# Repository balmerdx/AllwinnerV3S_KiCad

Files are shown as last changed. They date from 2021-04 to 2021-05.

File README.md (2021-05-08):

# Balmer Allwinner V3S KICAD scematic & pcb

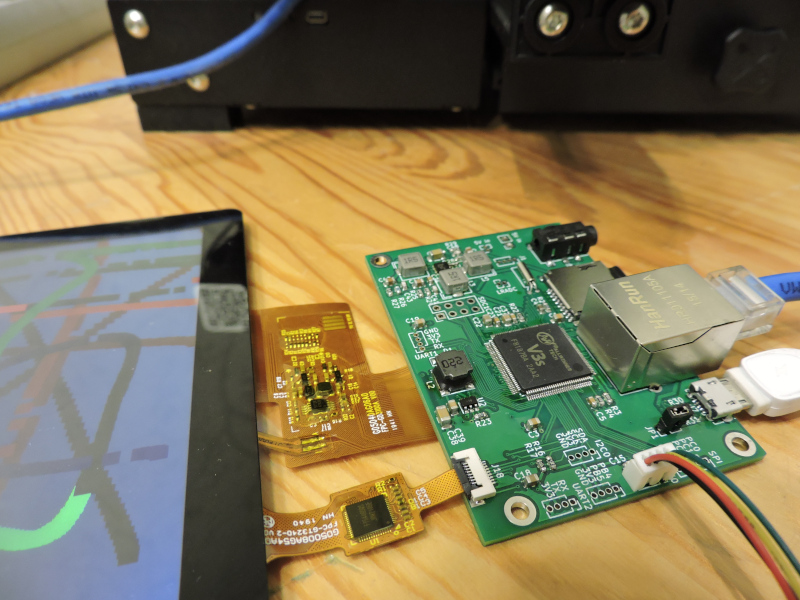
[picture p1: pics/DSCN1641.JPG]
Плата


Allwinner V3S - это пожалуй один из наиболее дешёвых system on chip для embedded linux.

Перечислю его ключевые особенности.
* встроенные 64 мегабайта DRAM
* RGB интерфейс для подключения дисплея
* встроенный PNY для Ethernet 100 Mbit
* USB 2.0 OTG
* встроенный DAC и усилитель для наушников

Это позволяет сделать достаточно дешёвый одноплатник.

Обратите внимание!!!! Плата разведена для Step-Down на EA3036. Микросхема EA3036C имеет несколько другой pinout. К сожалению мне прислали EA3036C, и поэтому на плате есть некрасивое место с её вкорячиванием.

Плата разведена под дисплей с 800x480 с capacitive touch (G05012AG02A1, G050AGZ085A1).

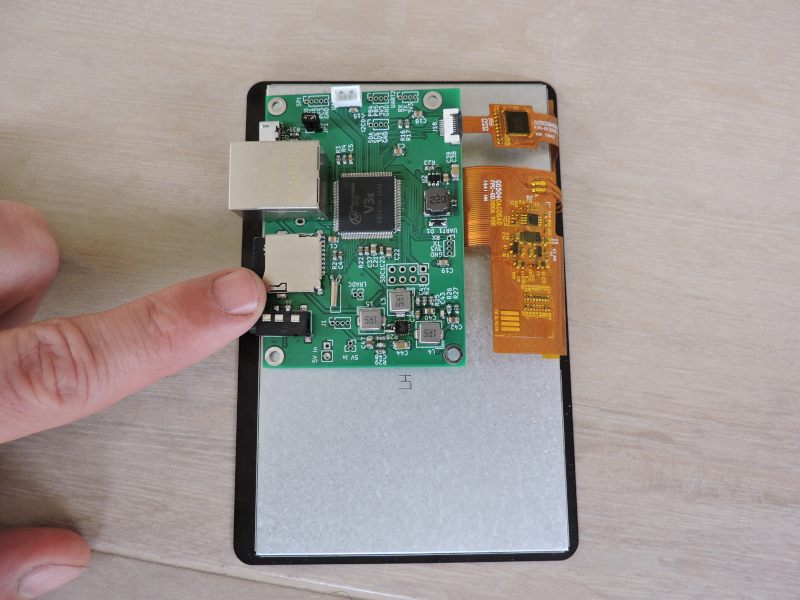
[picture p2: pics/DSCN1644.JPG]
Плата с подключённым дисплеем

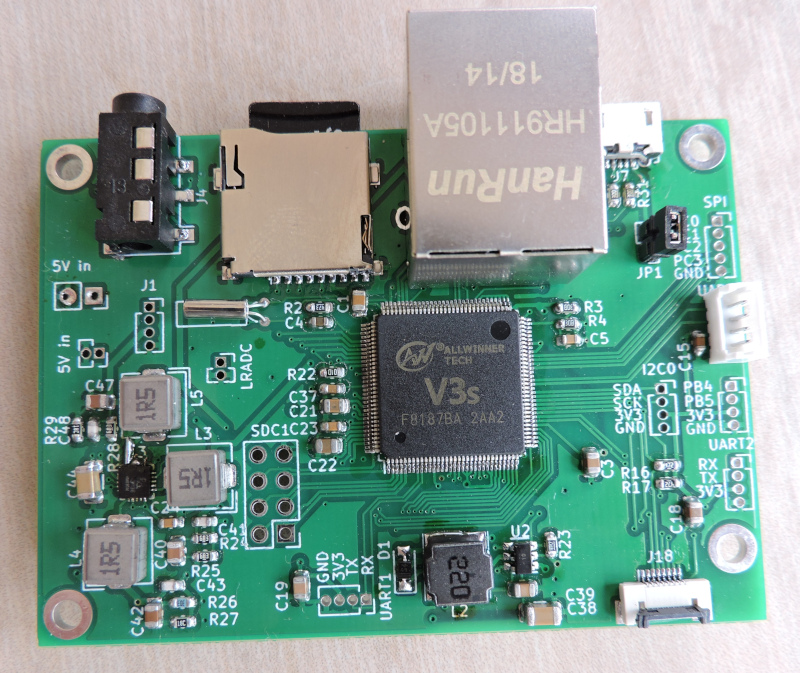
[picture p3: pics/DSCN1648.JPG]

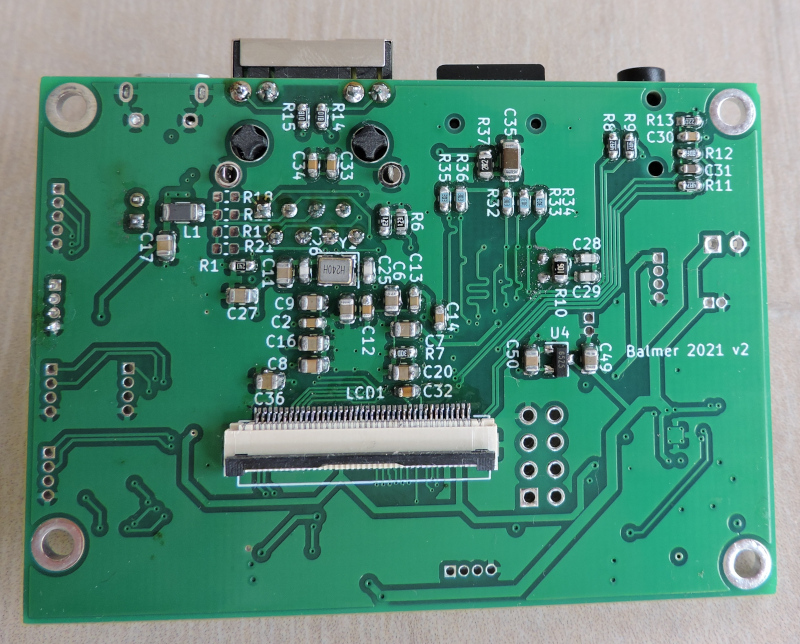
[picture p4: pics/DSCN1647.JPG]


То-же, самое но с корпусом.
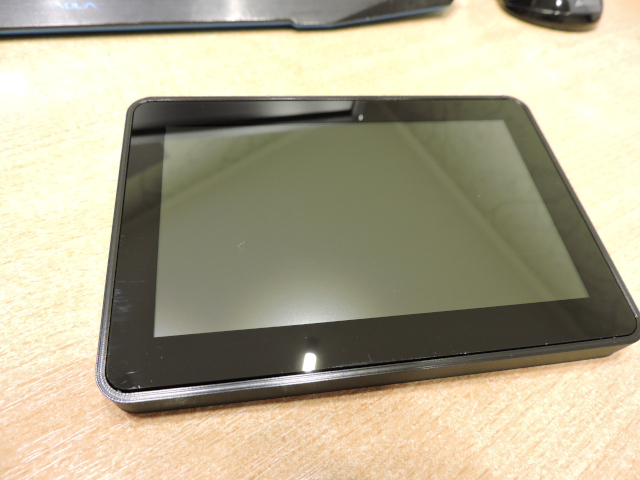
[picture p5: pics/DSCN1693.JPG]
В корпусе сверху

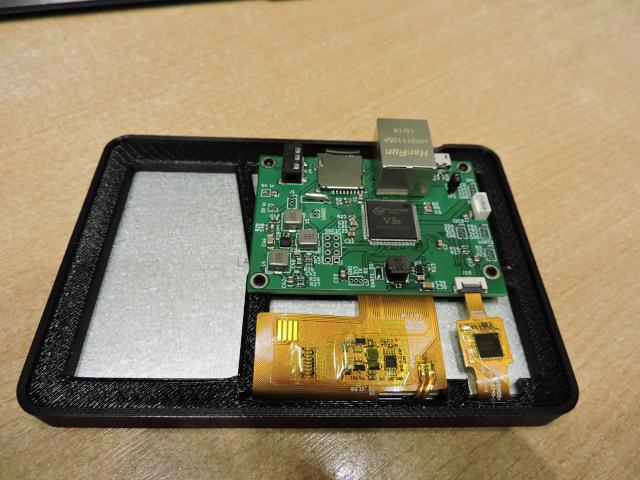
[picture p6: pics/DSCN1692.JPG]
В корпусе снизу


### Сравним с Lichee PI

По размеру мой вариант несколько больше. Но за счёт расположенных разъёмов конечный вариант будет явно компактнее. Разводка Lichee PI мне нравится как пример максимально плотного монтажа. Для отладки это нормально. Но в реальной жизни непонятно, что делать с этими случайным образом раскиданными разъёмами.

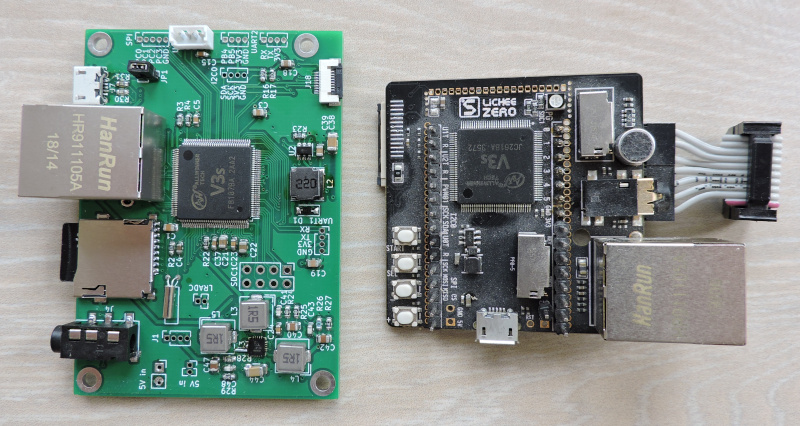
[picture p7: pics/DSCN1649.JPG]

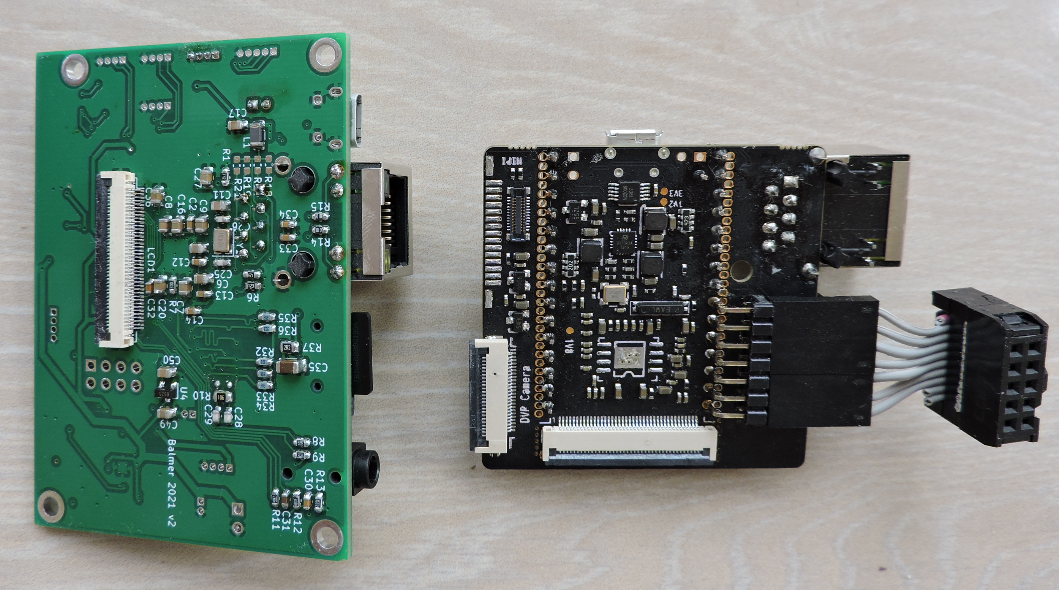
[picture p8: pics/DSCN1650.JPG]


### Информация
* [Схема в pdf формате](info/balmer_allwinner_v3s_v2.pdf)
* [Информация, как собирать linux](info/Buildroot_AllwinnerV3S.pdf)

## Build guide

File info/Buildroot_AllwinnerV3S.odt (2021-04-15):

О настройке buildroot для Allwinner V3S.

Как по порядку настроить buildroot c ядром 4.14 для того, чтобы работал дисплей с capacitive touch touch и WiFi.

Buildroot это достаточно удобная среда, для сборки embedded linux. Она объединяет вместе ядро линукса, uboot и busybox. Ядро 4.14 мне кажется всё ещё достаточно новым. Например Ubuntu, с которой я пишу текст имеет ядро 4.15.

# Первоначальная установка buildroot.

По ссылке https://github.com/Squonk42/buildroot-licheepi-zero есть buildroot заточенный для Allwinner V3S и Lichee PI. Поэтому копируем оттуда основную ветку и в корневой директории пишем:

make licheepi_zero_defconfig

make

И долго долго ждем, когда соберётся первоначальная версия. Она будет без работающего дисплея, но уже с uart/i2c/ethernet(проводной)/LRADC работающими.

Дальше можно проверить, что оно как-то работает.

Записать на SD карту можно например так:

sudo dd if=output/images/sdcard.img of=/dev/sdc bs=4M oflag=dsync

/dev/sdc - это имя вашей sd карты, надо быть акуратнее, чтобы случайно диск какой не отформатировать.

Подключать переходник USB<>UART надо к uart0, это пины IO-B09, IO-B08

После этого можно воткнуть SD карту, включить устройство и подсоединиться используя команды

cu -l /dev/ttyUSB0 -s 115200

screen /dev/ttySUSB0 115200

Login: root

Password: licheepi

# Инициализация дисплея в uboot.

Запускаем

make uboot-nconfig

выставляем такие значения

ARM architecture->

LCD panel timing details (x:800,y:480,depth:18,pclk_khz:33000,le:87,ri:40,up:31,lo:13,hs:1,vs:1,sync:3,vmode:0)

(PB4) LCD Panel backlight PWM

() LCD panel backlight pwm is inverted <- тут не должно быть галочки

Далее компилируем его

make uboot-rebuild

make

После записи на SD карту можно будет увидеть картинку пингвина (это uboot присует) и лог на экране, который уже linux пишет.

(Внимание! PB4 не используется для PWM в плате balmer_allwinner_v3s_v2)

# Настраиваем Capacitive touch screen.

В нашем случае он на FT5446, и для него подходят драйвера ft5x06 которые и так есть в linux. Надо только скомпилировать драйвера и приписать соответсвующие строчки описания железа в dts файл.

Нас интересуют следующие файлы:

sun8i-v3s-licheepi-zero.dts

sun8i-v3s.dtsi

В файле sun8i-v3s.dtsi в секции pio: надо определить секцию

edt_ft5x06_pins: edt_ft5x06_pins@0 {

pins = "PB0", "PB1";

function = "gpio_in";

};

Это наши пины для reset и interrupt для touch screen.

В файле sun8i-v3s-licheepi-zero.dts:

Добавить секцию (и убрать секцию со старым resistive touch в колторой ns2009 драйвера используются)

&i2c0 {

status = "okay";

polytouch: edt-ft5x06@38 {

compatible = "edt,edt-ft5406";

reg = <0x38>;

interrupt-parent = <&pio>;

interrupts = <1 3 IRQ_TYPE_EDGE_FALLING>; //PB3

reset-gpios = <&pio 1 2 GPIO_ACTIVE_LOW>; //PB2

pinctrl-names = "default";

pinctrl-0 = <&edt_ft5x06_pins>;

};

};

Находятся они по таким путям

output/build/linux-zero-4.14.y/arch/arm/boot/dts/sun8i-v3s.dtsi

output/build/linux-zero-4.14.y/arch/arm/boot/dts/sun8i-v3s-licheepi-zero.dts

Так-же надо разрешить наши touch драйвера (и запретить от resistive touch screen)

make linux-nconfig

И ищем там настройки touchscreen.

Device Drivers->Input device support->Touchscreens

Nsiway NS2009 touchscreen - убрать звездочку

EDT FocalTech FT5x06 I2C Touchscreen support - поставить звездочку

после этого пересобираем

make linux-rebuild

make

Touch подключается так (можно по схеме посмотреть)

PB3 - PIN4 INT

PB2 - PIN3 RST

PB6 - PIN6 SCL

PB7 - PIN5 SDA

Ну и GND, VCC соответственно к земле и 3.3V

Само устройство будет по пути.

/dev/input/event1

Можно также запустить на устройстве.

i2cdetect -y 0

и увидеть

0 1 2 3 4 5 6 7 8 9 a b c d e f

00: -- -- -- -- -- -- -- -- -- -- -- -- --

10: -- -- -- -- -- -- -- -- -- -- -- -- -- -- -- --

20: -- -- -- -- -- -- -- -- -- -- -- -- -- -- -- --

30: -- -- -- -- -- -- -- -- UU -- -- -- -- -- -- --

40: -- -- -- -- -- -- -- -- 48 -- -- -- -- -- -- --

50: -- -- -- -- -- -- -- -- -- -- -- -- -- -- -- --

60: -- -- -- -- -- -- -- -- -- -- -- -- -- -- -- --

70: -- -- -- -- -- -- -- --

UU на адресе 0x38 значит, что он используется драйвером Touch.

# Настройка WiFi.

Собственно говоря тут всё работает практически «из коробки». Надо лишь загрузить драйвер r8723bs.ko (т. к. он не встроен в ядро) и настроить wpa_supplicant.

Для этого добавил файл /etc/init.d/S30wifi_driver в процесс загрузки.

Этот файл можно ручками скопировать после сборки. Но лично мне кажется, что лучше встроить это в процесс сборки, тем более buildroot предлагает такой вариант.

В файле .config изменяем на BR2_ROOTFS_OVERLAY="../buildroot_additional/rootfs_overlay" и всё, что в папке rootfs_overlay будет копироваться на наш диск с linux.

Далее, необходимо добавить и настроить wpa_supplicant.

Запускается он в файле rootfs_overlay/etc/network/interfaces

Файл /etc/balmer_SSID.conf - это имя нашей WiFi сети и пароль к ней.

Герерируется этот файл при помощи команды wpa_passphrase wifi_name wifi_password > balmer_SSID.conf

После этого делаем make и в нашем образе диска должны появиться файлы

/etc/balmer_SSID.conf

/etc/init.d/S30wifi_driver

/etc/network/interfaces

После этого WiFi будет запускаться и подключаться в процессе загрузки устройства.

После загрузки можно запустить ifconfig и увидеть, что появился wlan0

wlan0 Link encap:Ethernet HWaddr CC:D2:9B:4B:8C:AD

inet addr:192.168.1.46 Bcast:192.168.1.255 Mask:255.255.255.0

либо воспользоваться командами ping или wget которые есть в сборке по умолчанию.

# Как отключить вывод консоли на экран.

В файле board/licheepi/boot.cmd заменяем первую строчку на такую

setenv bootargs console=ttyS0,115200 panic=5 rootwait consoleblank=0 vt.global_cursor_default=0 root=/dev/mmcblk0p2 earlyprintk rw

Это отключит как вывод консольных сообщений на экран, так и мигающий курсор.

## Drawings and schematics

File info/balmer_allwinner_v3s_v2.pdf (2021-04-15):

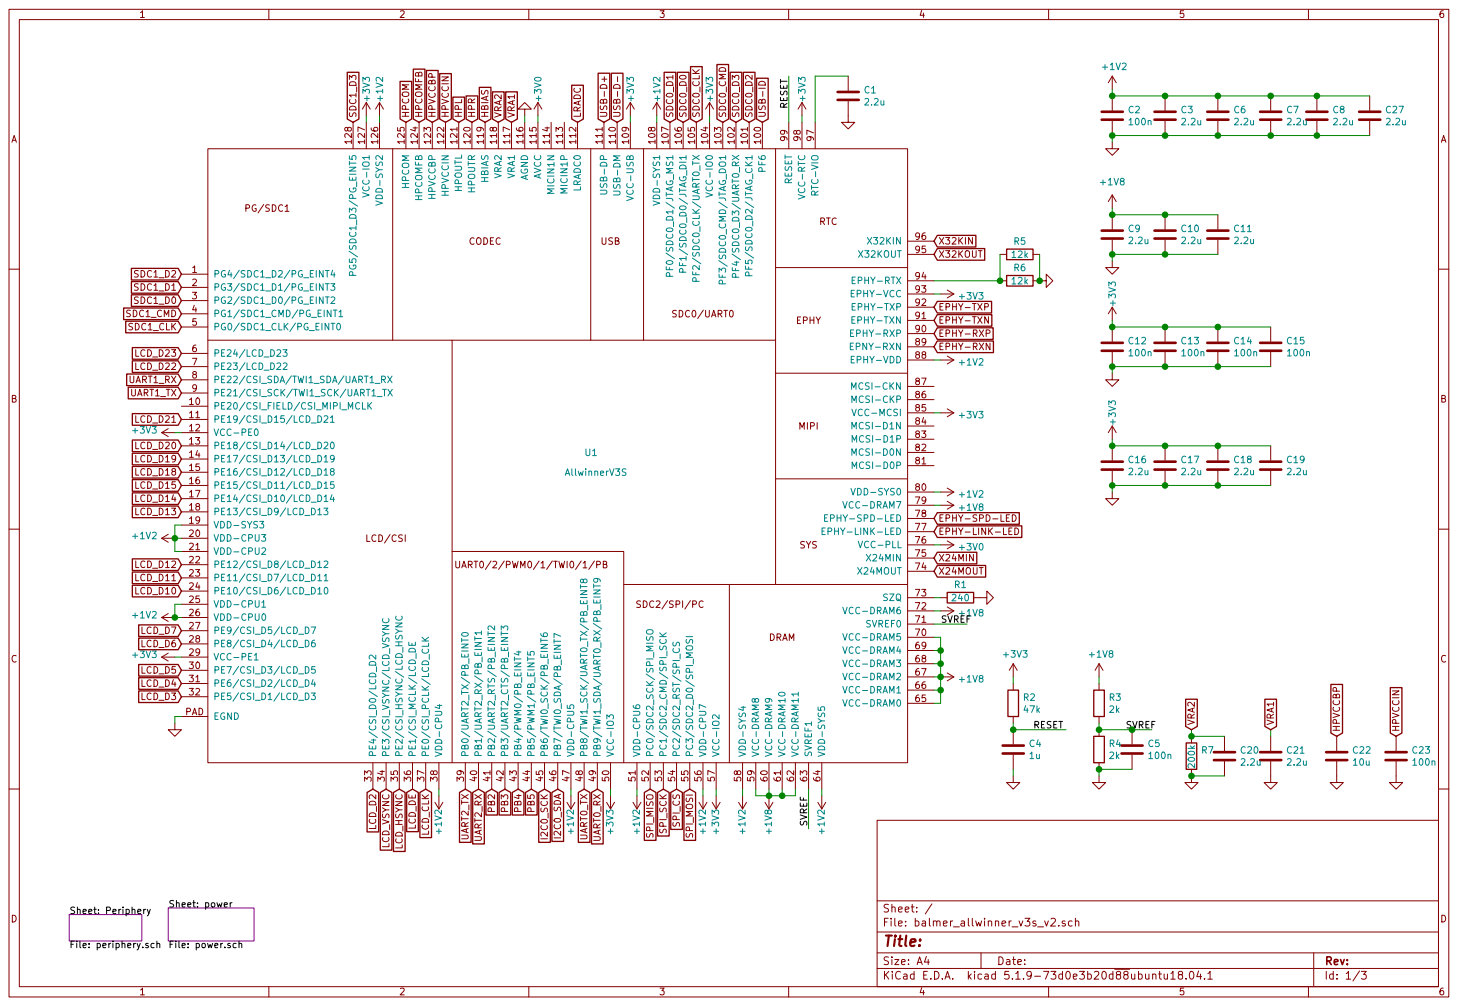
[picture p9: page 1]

CODEC

USB SDC0/UART0 SDC2/SPI/PC U1 AllwinnerV3S | SYS UART0/2/PWM0/1/TWI0/1/PB

File: balmer_allwinner_v3s_v2.sch Sheet: / Sheet: power

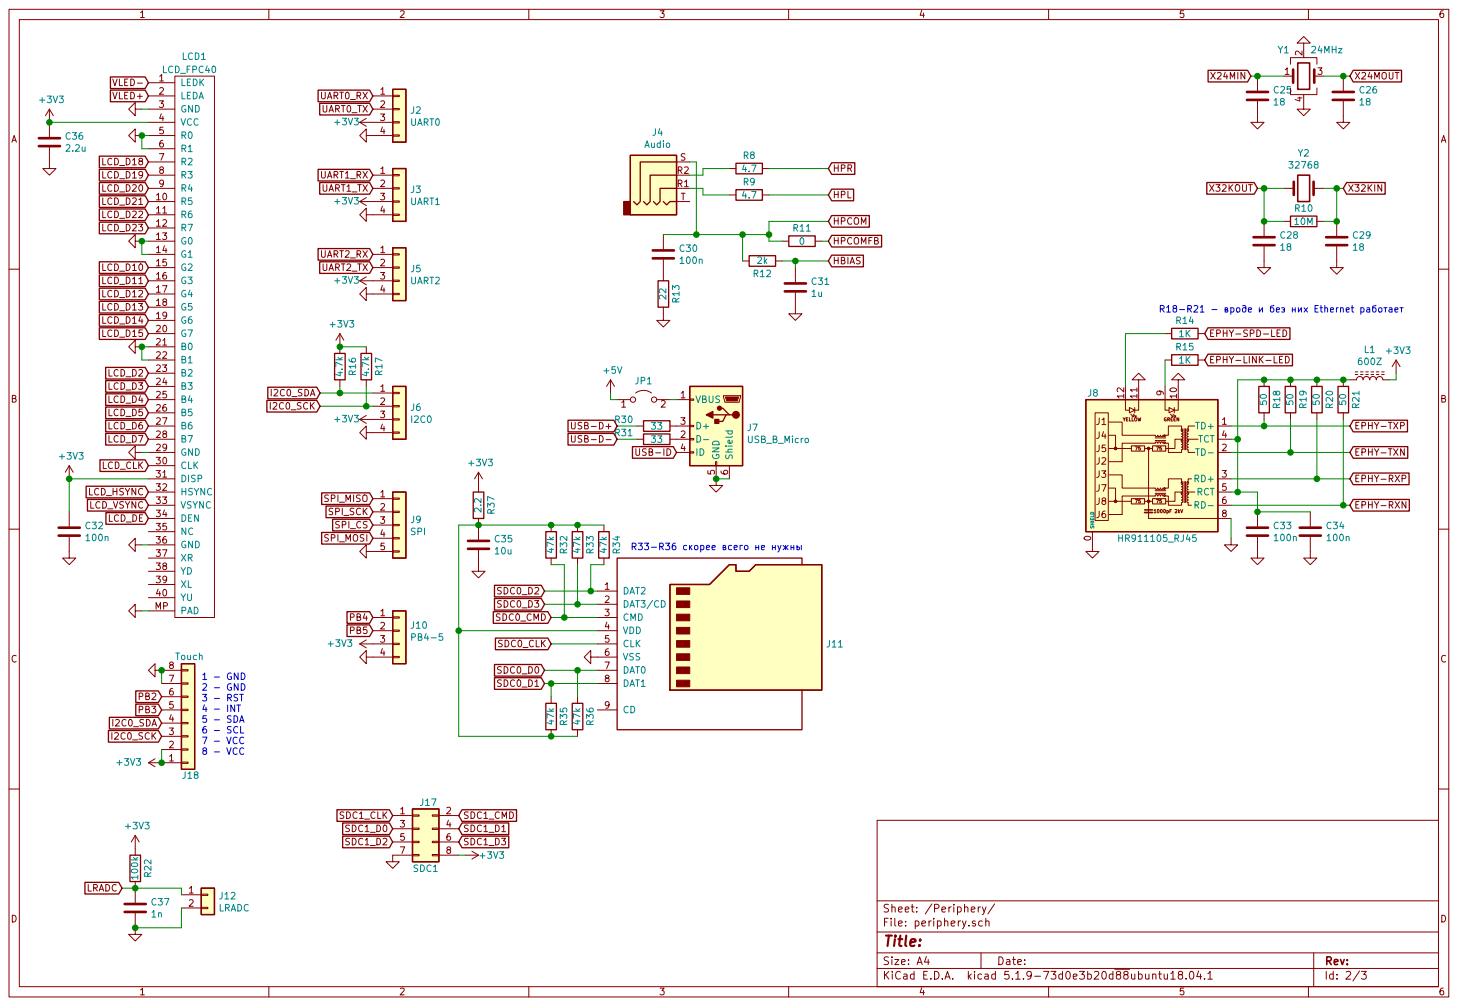
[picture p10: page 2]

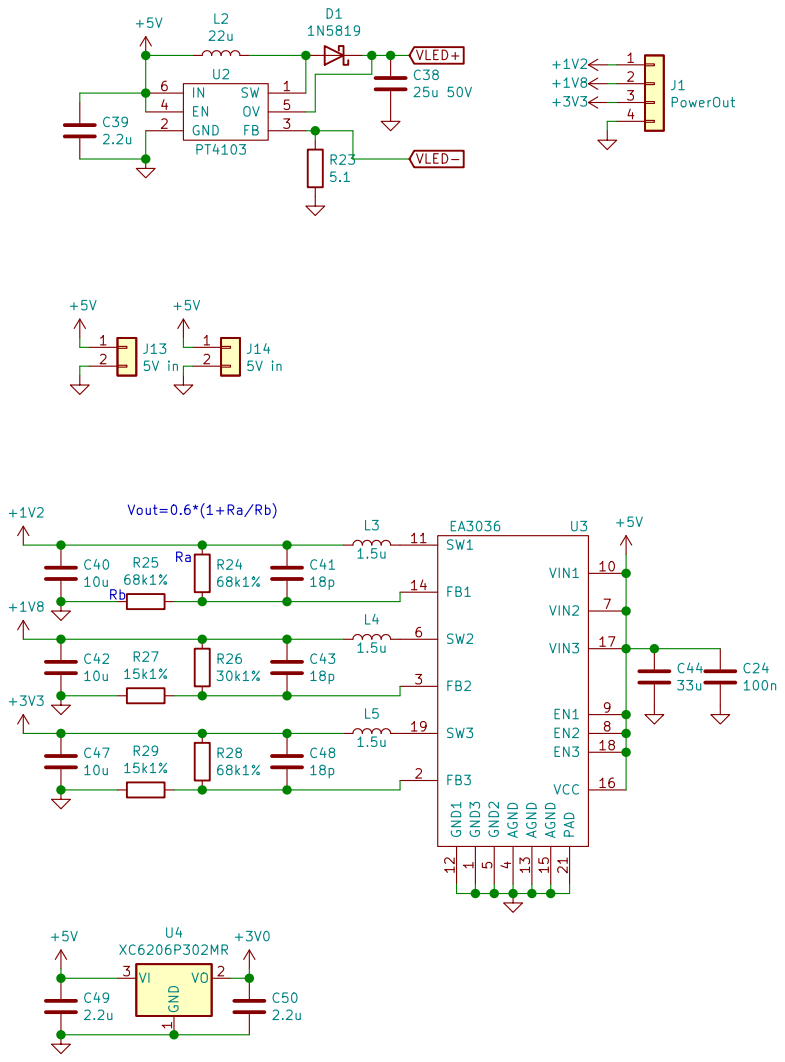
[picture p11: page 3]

1 VIN1 10 SW1 11 GND1 12 AGND 13 FB1 14 AGND 15 VCC 16 VIN3 17 EN3 18 SW3 19 FB3 2 PAD 21 FB2 3 AGND

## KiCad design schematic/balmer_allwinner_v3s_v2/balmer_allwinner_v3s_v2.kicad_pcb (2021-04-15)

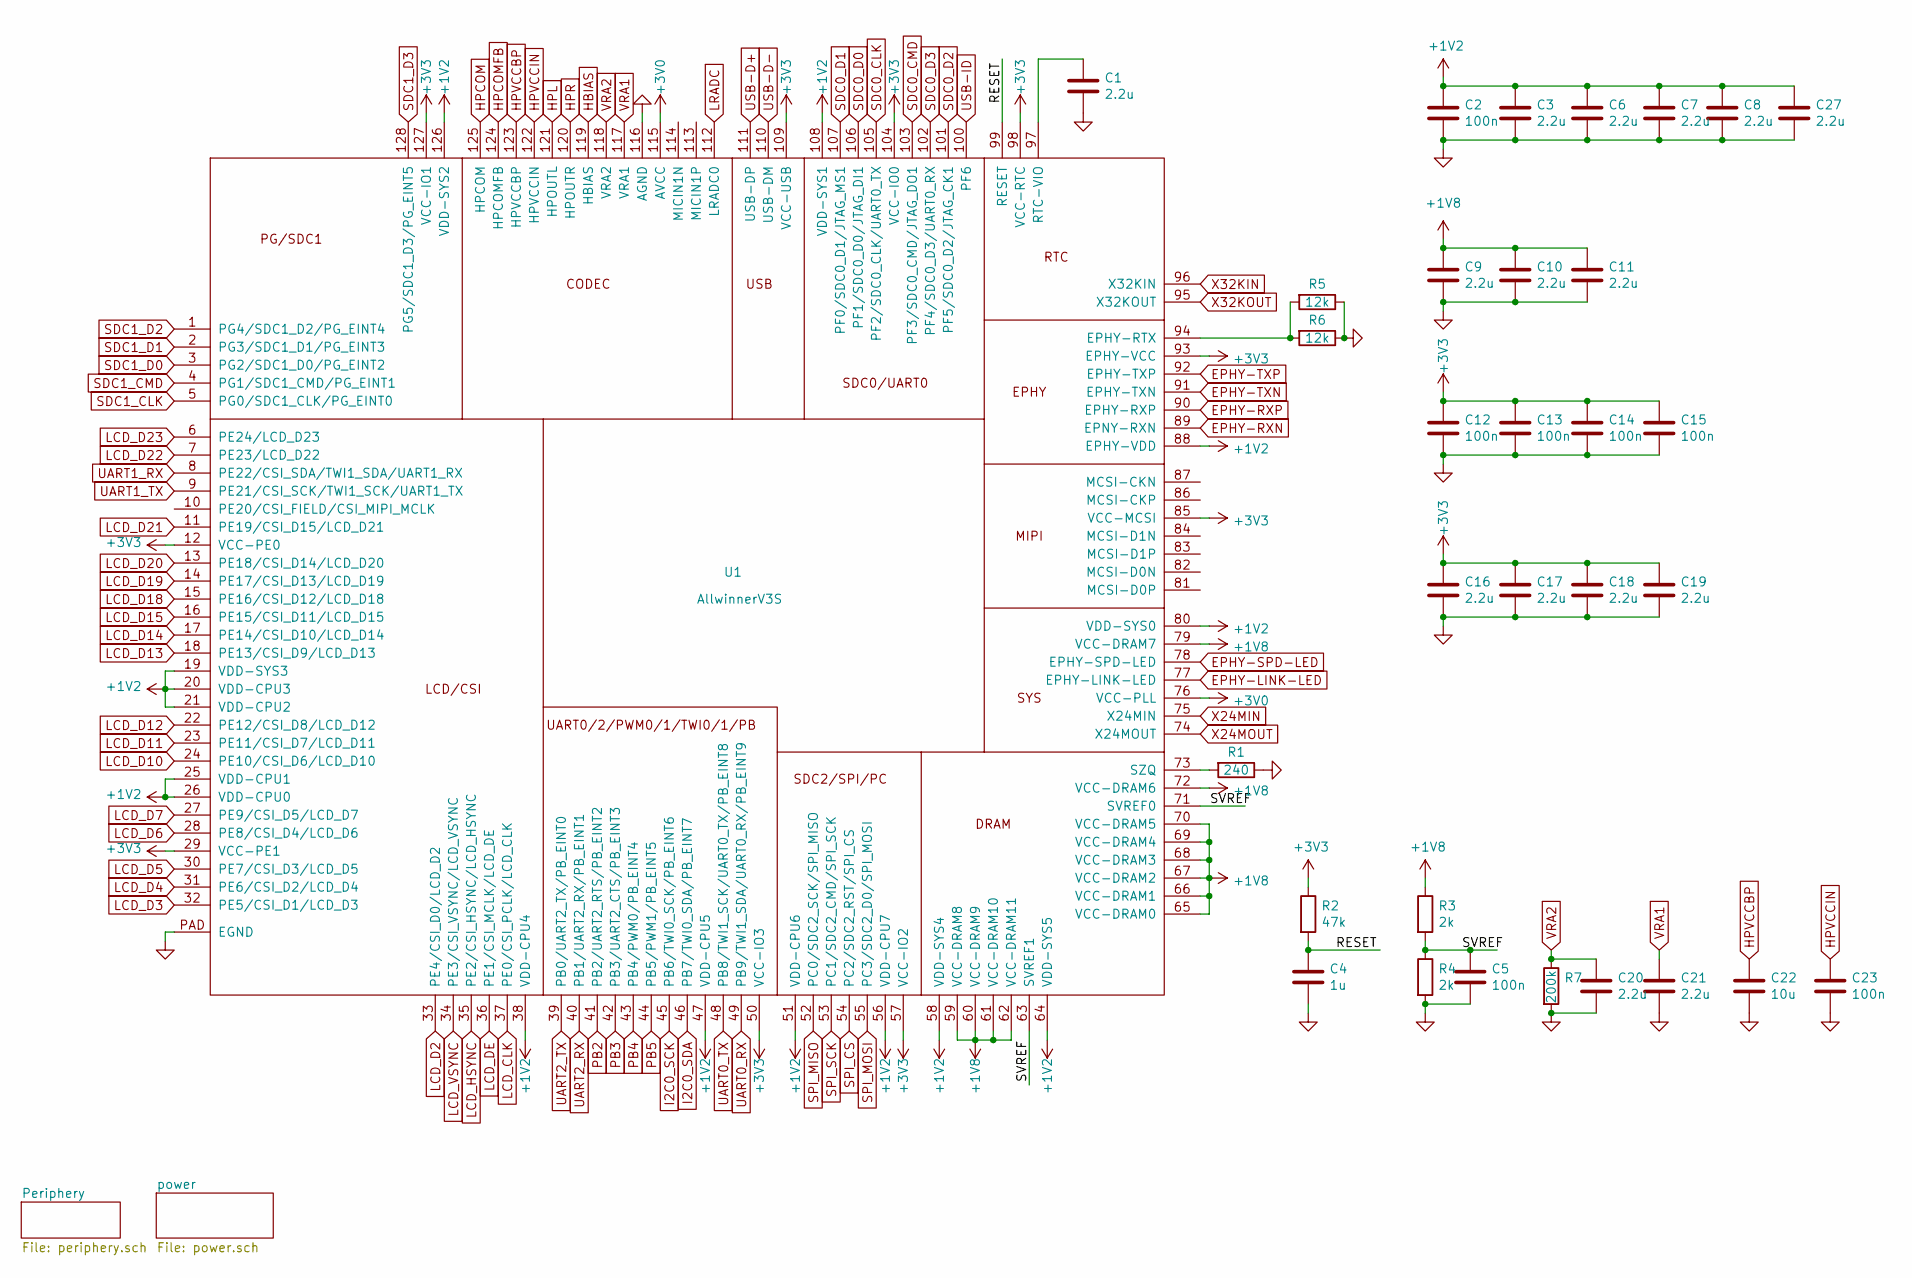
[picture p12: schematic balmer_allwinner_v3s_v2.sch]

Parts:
C1, C3, C6, C7, C8, C9, C10, C11, C16, C17, C18, C19, C20, C21, C27: 2.2u; C_0805_2012Metric
C2, C5, C12, C13, C14, C15, C23: 100n; C_0603_1608Metric
C4: 1u; C_0603_1608Metric
C22: 10u; C_0805_2012Metric
R1: 240; R_0603_1608Metric
R2: 47k; R_0603_1608Metric
R3, R4: 2k; R_0603_1608Metric
R5, R6: 12k; R_0603_1608Metric
R7: 200k; R_0603_1608Metric
U1: AllwinnerV3S; eLQFP-128_14x14mm_P0.4mm

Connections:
+1V2: C2.1, C3.1, C6.1, C7.1, C8.1, C27.1, U1.19 (VDD-SYS3), U1.20 (VDD-CPU3), U1.21 (VDD-CPU2), U1.25 (VDD-CPU1), U1.26 (VDD-CPU0), U1.38 (VDD-CPU4), U1.47 (VDD-CPU5), U1.51 (VDD-CPU6), U1.56 (VDD-CPU7), U1.58 (VDD-SYS4), U1.64 (VDD-SYS5), U1.80 (VDD-SYS0), U1.88 (EPHY-VDD), U1.108 (VDD-SYS1), U1.126 (VDD-SYS2); also elsewhere on the board
+1V8: C9.1, C10.1, C11.1, R3.1, U1.59 (VCC-DRAM8), U1.60 (VCC-DRAM9), U1.61 (VCC-DRAM10), U1.62 (VCC-DRAM11), U1.65 (VCC-DRAM0), U1.66 (VCC-DRAM1), U1.67 (VCC-DRAM2), U1.68 (VCC-DRAM3), U1.69 (VCC-DRAM4), U1.70 (VCC-DRAM5), U1.72 (VCC-DRAM6), U1.79 (VCC-DRAM7); also elsewhere on the board
+3V0: U1.76 (VCC-PLL), U1.115 (AVCC); also elsewhere on the board
+3V3: C12.1, C13.1, C14.1, C15.1, C16.1, C17.1, C18.1, C19.1, R2.1, U1.12 (VCC-PE0), U1.29 (VCC-PE1), U1.50 (VCC-IO3), U1.57 (VCC-IO2), U1.85 (VCC-MCSI), U1.93 (EPHY-VCC), U1.98 (VCC-RTC), U1.104 (VCC-IO0), U1.109 (VCC-USB), U1.127 (VCC-IO1); also elsewhere on the board
/RESET: C4.1, R2.2, U1.99 (RESET)
/SVREF: C5.1, R3.2, R4.1, U1.63 (SVREF1), U1.71 (SVREF0)
EPHY-LINK-LED: U1.77 (EPHY-LINK-LED); also elsewhere on the board
EPHY-RXN: U1.89 (EPNY-RXN); also elsewhere on the board
EPHY-RXP: U1.90 (EPHY-RXP); also elsewhere on the board
EPHY-SPD-LED: U1.78 (EPHY-SPD-LED); also elsewhere on the board
EPHY-TXN: U1.91 (EPHY-TXN); also elsewhere on the board
EPHY-TXP: U1.92 (EPHY-TXP); also elsewhere on the board
GND: C1.2, C2.2, C3.2, C4.2, C5.2, C6.2, C7.2, C8.2, C9.2, C10.2, C11.2, C12.2, C13.2, C14.2, C15.2, C16.2, C17.2, C18.2, C19.2, C20.2, C21.2, C22.2, C23.2, C27.2, R1.1, R4.2, R5.1, R6.1, R7.2, U1.116 (AGND), U1.PAD (EGND); also elsewhere on the board
HBIAS: U1.119 (HBIAS); also elsewhere on the board
HPCOM: U1.125 (HPCOM); also elsewhere on the board
HPCOMFB: U1.124 (HPCOMFB); also elsewhere on the board
HPL: U1.121 (HPOUTL); also elsewhere on the board
HPR: U1.120 (HPOUTR); also elsewhere on the board
HPVCCBP: C22.1, U1.123 (HPVCCBP)
HPVCCIN: C23.1, U1.122 (HPVCCIN)
I2C0_SCK: U1.45 (PB6/TWI0_SCK/PB_EINT6); also elsewhere on the board
I2C0_SDA: U1.46 (PB7/TWI0_SDA/PB_EINT7); also elsewhere on the board
LCD_CLK: U1.37 (PE0/CSI_PCLK/LCD_CLK); also elsewhere on the board
LCD_D2: U1.33 (PE4/CSI_D0/LCD_D2); also elsewhere on the board
LCD_D3: U1.32 (PE5/CSI_D1/LCD_D3); also elsewhere on the board
LCD_D4: U1.31 (PE6/CSI_D2/LCD_D4); also elsewhere on the board
LCD_D5: U1.30 (PE7/CSI_D3/LCD_D5); also elsewhere on the board
LCD_D6: U1.28 (PE8/CSI_D4/LCD_D6); also elsewhere on the board
LCD_D7: U1.27 (PE9/CSI_D5/LCD_D7); also elsewhere on the board
LCD_D10: U1.24 (PE10/CSI_D6/LCD_D10); also elsewhere on the board
LCD_D11: U1.23 (PE11/CSI_D7/LCD_D11); also elsewhere on the board
LCD_D12: U1.22 (PE12/CSI_D8/LCD_D12); also elsewhere on the board
LCD_D13: U1.18 (PE13/CSI_D9/LCD_D13); also elsewhere on the board
LCD_D14: U1.17 (PE14/CSI_D10/LCD_D14); also elsewhere on the board
LCD_D15: U1.16 (PE15/CSI_D11/LCD_D15); also elsewhere on the board
LCD_D18: U1.15 (PE16/CSI_D12/LCD_D18); also elsewhere on the board
LCD_D19: U1.14 (PE17/CSI_D13/LCD_D19); also elsewhere on the board
LCD_D20: U1.13 (PE18/CSI_D14/LCD_D20); also elsewhere on the board
LCD_D21: U1.11 (PE19/CSI_D15/LCD_D21); also elsewhere on the board
LCD_D22: U1.7 (PE23/LCD_D22); also elsewhere on the board
LCD_D23: U1.6 (PE24/LCD_D23); also elsewhere on the board
LCD_DE: U1.36 (PE1/CSI_MCLK/LCD_DE); also elsewhere on the board
LCD_HSYNC: U1.35 (PE2/CSI_HSYNC/LCD_HSYNC); also elsewhere on the board
LCD_VSYNC: U1.34 (PE3/CSI_VSYNC/LCD_VSYNC); also elsewhere on the board
LRADC: U1.112 (LRADC0); also elsewhere on the board
unnamed: C1.1, U1.97 (RTC-VIO)
unnamed: R1.2, U1.73 (SZQ)
unnamed: R5.2, R6.2, U1.94 (EPHY-RTX)
PB2: U1.41 (PB2/UART2_RTS/PB_EINT2); also elsewhere on the board
PB3: U1.42 (PB3/UART2_CTS/PB_EINT3); also elsewhere on the board
PB4: U1.43 (PB4/PWM0/PB_EINT4); also elsewhere on the board
PB5: U1.44 (PB5/PWM1/PB_EINT5); also elsewhere on the board
SDC0_CLK: U1.105 (PF2/SDC0_CLK/UART0_TX); also elsewhere on the board
SDC0_CMD: U1.103 (PF3/SDC0_CMD/JTAG_DO1); also elsewhere on the board
SDC0_D0: U1.106 (PF1/SDC0_D0/JTAG_DI1); also elsewhere on the board
SDC0_D1: U1.107 (PF0/SDC0_D1/JTAG_MS1); also elsewhere on the board
SDC0_D2: U1.101 (PF5/SDC0_D2/JTAG_CK1); also elsewhere on the board
SDC0_D3: U1.102 (PF4/SDC0_D3/UART0_RX); also elsewhere on the board
SDC1_CLK: U1.5 (PG0/SDC1_CLK/PG_EINT0); also elsewhere on the board
SDC1_CMD: U1.4 (PG1/SDC1_CMD/PG_EINT1); also elsewhere on the board
SDC1_D0: U1.3 (PG2/SDC1_D0/PG_EINT2); also elsewhere on the board
SDC1_D1: U1.2 (PG3/SDC1_D1/PG_EINT3); also elsewhere on the board
SDC1_D2: U1.1 (PG4/SDC1_D2/PG_EINT4); also elsewhere on the board
SDC1_D3: U1.128 (PG5/SDC1_D3/PG_EINT5); also elsewhere on the board
SPI_CS: U1.54 (PC2/SDC2_RST/SPI_CS); also elsewhere on the board
SPI_MISO: U1.52 (PC0/SDC2_SCK/SPI_MISO); also elsewhere on the board
SPI_MOSI: U1.55 (PC3/SDC2_D0/SPI_MOSI); also elsewhere on the board
SPI_SCK: U1.53 (PC1/SDC2_CMD/SPI_SCK); also elsewhere on the board
UART0_RX: U1.49 (PB9/TWI1_SDA/UART0_RX/PB_EINT9); also elsewhere on the board
UART0_TX: U1.48 (PB8/TWI1_SCK/UART0_TX/PB_EINT8); also elsewhere on the board
UART1_RX: U1.8 (PE22/CSI_SDA/TWI1_SDA/UART1_RX); also elsewhere on the board
UART1_TX: U1.9 (PE21/CSI_SCK/TWI1_SCK/UART1_TX); also elsewhere on the board
UART2_RX: U1.40 (PB1/UART2_RX/PB_EINT1); also elsewhere on the board
UART2_TX: U1.39 (PB0/UART2_TX/PB_EINT0); also elsewhere on the board
USB-D+: U1.111 (USB-DP); also elsewhere on the board
USB-D-: U1.110 (USB-DM); also elsewhere on the board
USB-ID: U1.100 (PF6); also elsewhere on the board
VRA1: C21.1, U1.117 (VRA1)
VRA2: C20.1, R7.1, U1.118 (VRA2)
X24MIN: U1.75 (X24MIN); also elsewhere on the board
X24MOUT: U1.74 (X24MOUT); also elsewhere on the board
X32KIN: U1.96 (X32KIN); also elsewhere on the board
X32KOUT: U1.95 (X32KOUT); also elsewhere on the board

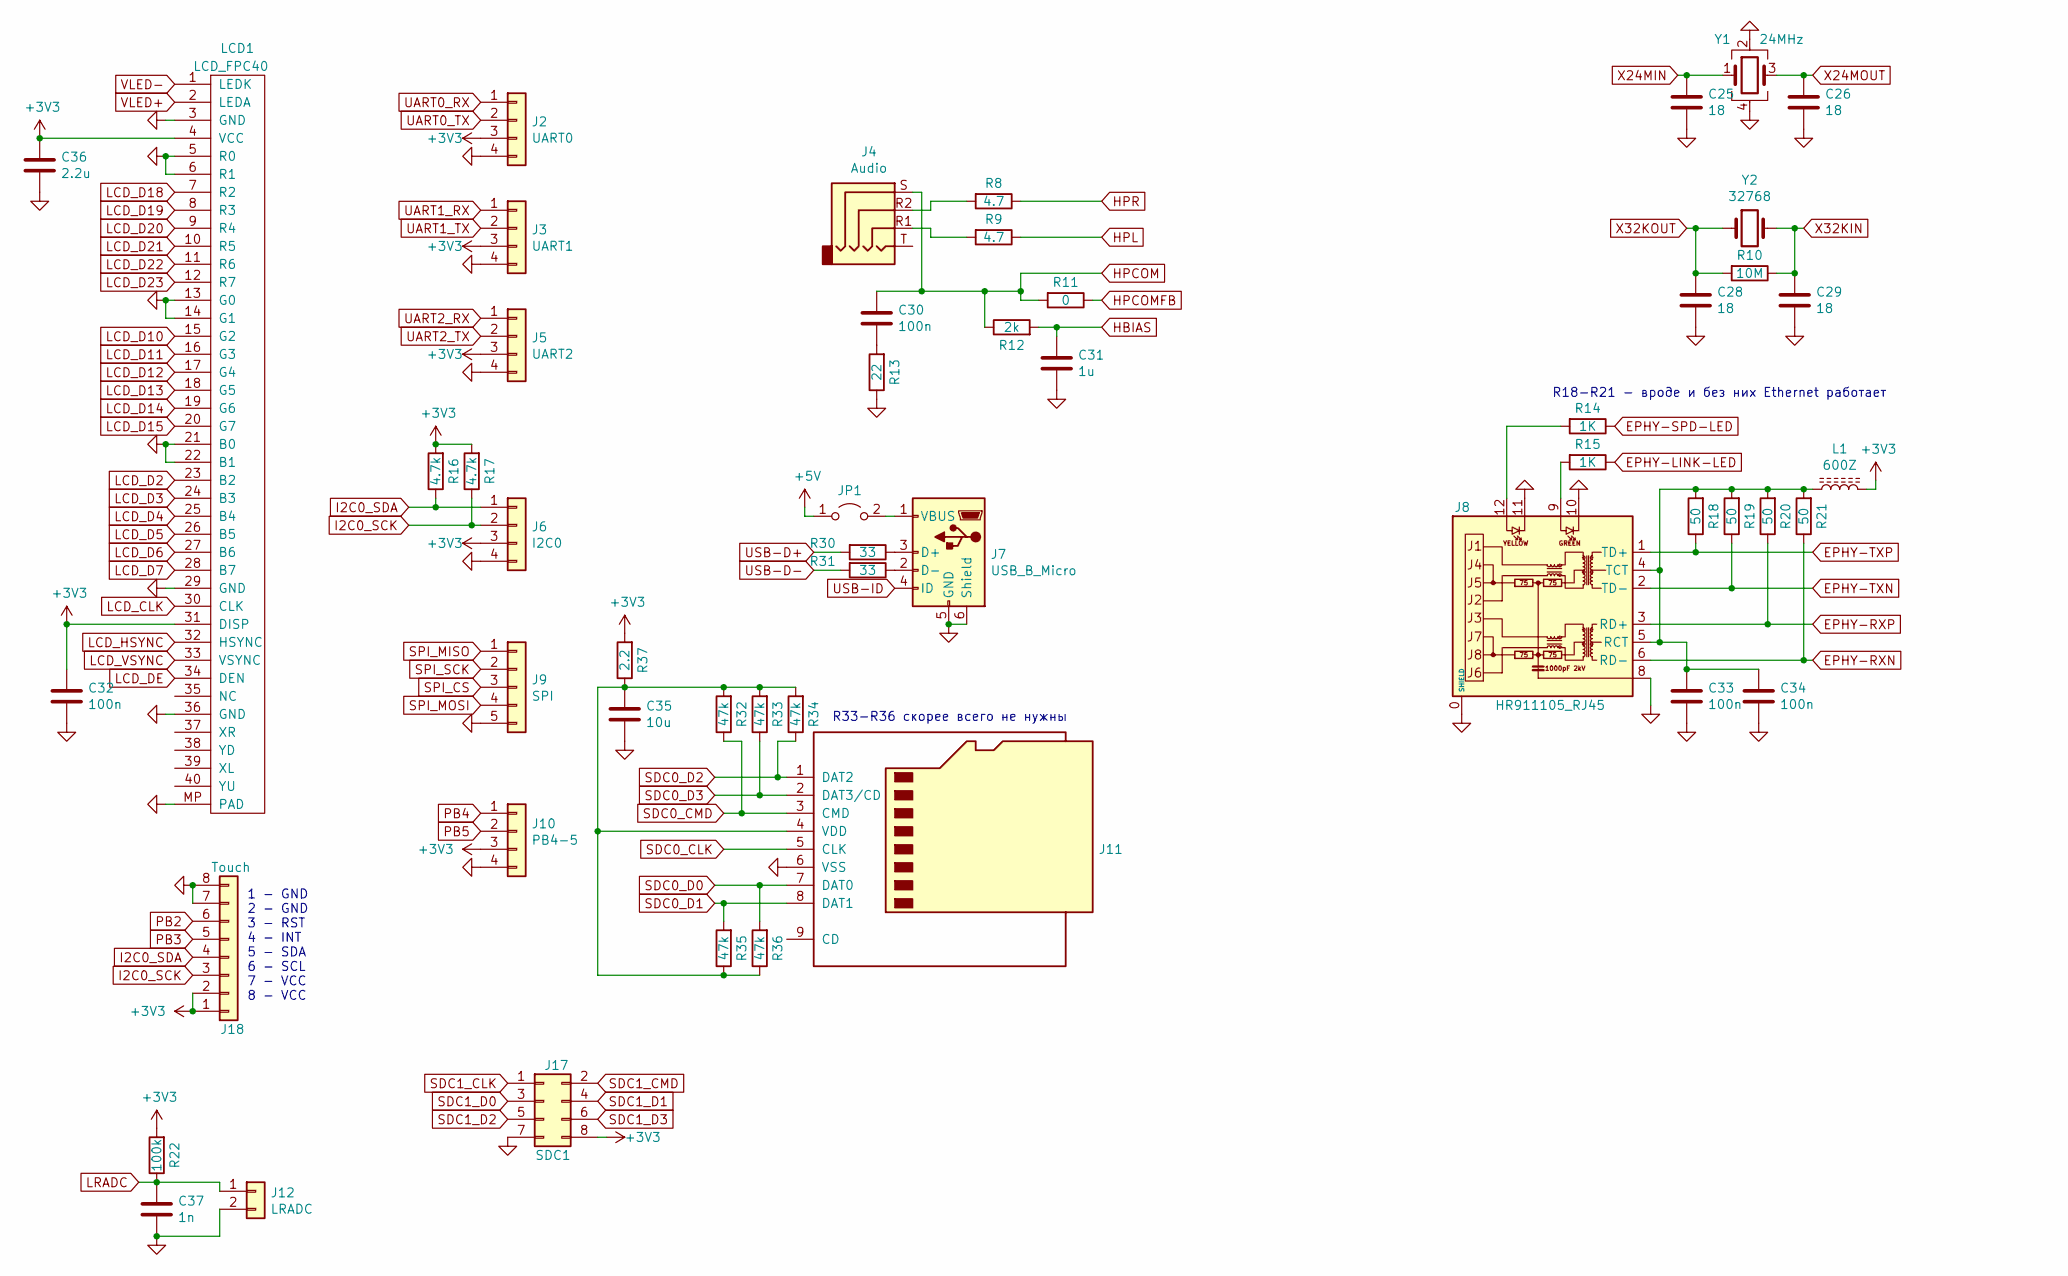
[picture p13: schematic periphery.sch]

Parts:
C25, C26, C28, C29: 18; C_0603_1608Metric
C30, C32, C33, C34: 100n; C_0603_1608Metric
C31: 1u; C_0603_1608Metric
C35: 10u; C_1206_3216Metric
C36: 2.2u; C_0805_2012Metric
C37: 1n; C_0603_1608Metric
J2: UART0; PinSocket_1x04_P1.27mm_Vertical
J3: UART1; PinSocket_1x04_P1.27mm_Vertical
J4: Audio; Jack_3.5mm_PJ320D_Horizontal
J5: UART2; PinSocket_1x04_P1.27mm_Vertical
J6: I2C0; PinSocket_1x04_P1.27mm_Vertical
J7: USB_B_Micro; USB_Micro-B_Molex-105017-0001
J8: HR911105_RJ45
J9: SPI; PinSocket_1x05_P1.27mm_Vertical
J10: PB4-5; PinSocket_1x04_P1.27mm_Vertical
J11: Micro_SD_Card_Ebay; Conn_uSDcard
J12: LRADC; PinSocket_1x02_P1.27mm_Vertical
J17: SDC1; PinHeader_2x04_P2.54mm_Vertical
J18: Touch; Hirose_FH12-8S-0.5SH_1x08-1MP_P0.50mm_Horizontal
JP1: Jumper_2_Open; PinHeader_1x02_P2.00mm_Vertical
L1: 600Z; L_1206_3216Metric
LCD1: LCD_FPC40; Hirose_FH12-40S-0.5SH_1x40-1MP_P0.50mm_Horizontal
R8, R9: 4.7; R_0603_1608Metric
R10: 10M; R_0805_2012Metric
R11: 0; R_0603_1608Metric
R12: 2k; R_0603_1608Metric
R13: 22; R_0603_1608Metric
R14, R15: 1K; R_0603_1608Metric
R16, R17: 4.7k; R_0603_1608Metric
R18, R19, R20, R21: 50; R_0603_1608Metric
R22: 100k; R_0603_1608Metric
R30, R31: 33; R_0603_1608Metric
R32, R33, R34, R35, R36: 47k; R_0603_1608Metric
R37: 2.2; R_0805_2012Metric
Y1: 24MHz; Crystal_SMD_3225-4Pin_3.2x2.5mm
Y2: 32768; Crystal_C26-LF_D2.1mm_L6.5mm_Horizontal

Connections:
+3V3: C32.1, C36.1, J2.3, J3.3, J5.3, J6.3, J10.3, J17.8, J18.1, J18.2, L1.2, LCD1.4 (VCC), LCD1.31 (DISP), R16.2, R17.2, R22.2, R37.2; also elsewhere on the board
+5V: JP1.1 (A); also elsewhere on the board
EPHY-LINK-LED: R15.1; also elsewhere on the board
EPHY-RXN: J8.6 (RD-), R21.1; also elsewhere on the board
EPHY-RXP: J8.3 (RD+), R20.1; also elsewhere on the board
EPHY-SPD-LED: R14.1; also elsewhere on the board
EPHY-TXN: J8.2 (TD-), R19.1; also elsewhere on the board
EPHY-TXP: J8.1 (TD+), R18.1; also elsewhere on the board
GND: C25.2, C26.2, C28.2, C29.2, C31.2, C32.2, C33.2, C34.2, C35.2, C36.2, C37.2, J2.4, J3.4, J5.4, J6.4, J7.5 (GND), J7.6 (Shield), J8.0 (SHIELD), J8.8, J8.10, J8.11, J9.5, J10.4, J11.6 (VSS), J12.2, J17.7, J18.7, J18.8, LCD1.3 (GND), LCD1.5 (R0), LCD1.6 (R1), LCD1.13 (G0), LCD1.14 (G1), LCD1.21 (B0), LCD1.22 (B1), LCD1.29 (GND), LCD1.36 (GND), LCD1.MP (PAD), R13.1, Y1.2, Y1.4; also elsewhere on the board
HBIAS: C31.1, R12.2; also elsewhere on the board
HPCOM: C30.1, J4.S, R11.2, R12.1; also elsewhere on the board
HPCOMFB: R11.1; also elsewhere on the board
HPL: R9.1; also elsewhere on the board
HPR: R8.1; also elsewhere on the board
I2C0_SCK: J6.2, J18.3, R17.1; also elsewhere on the board
I2C0_SDA: J6.1, J18.4, R16.1; also elsewhere on the board
LCD_CLK: LCD1.30 (CLK); also elsewhere on the board
LCD_D2: LCD1.23 (B2); also elsewhere on the board
LCD_D3: LCD1.24 (B3); also elsewhere on the board
LCD_D4: LCD1.25 (B4); also elsewhere on the board
LCD_D5: LCD1.26 (B5); also elsewhere on the board
LCD_D6: LCD1.27 (B6); also elsewhere on the board
LCD_D7: LCD1.28 (B7); also elsewhere on the board
LCD_D10: LCD1.15 (G2); also elsewhere on the board
LCD_D11: LCD1.16 (G3); also elsewhere on the board
LCD_D12: LCD1.17 (G4); also elsewhere on the board
LCD_D13: LCD1.18 (G5); also elsewhere on the board
LCD_D14: LCD1.19 (G6); also elsewhere on the board
LCD_D15: LCD1.20 (G7); also elsewhere on the board
LCD_D18: LCD1.7 (R2); also elsewhere on the board
LCD_D19: LCD1.8 (R3); also elsewhere on the board
LCD_D20: LCD1.9 (R4); also elsewhere on the board
LCD_D21: LCD1.10 (R5); also elsewhere on the board
LCD_D22: LCD1.11 (R6); also elsewhere on the board
LCD_D23: LCD1.12 (R7); also elsewhere on the board
LCD_DE: LCD1.34 (DEN); also elsewhere on the board
LCD_HSYNC: LCD1.32 (HSYNC); also elsewhere on the board
LCD_VSYNC: LCD1.33 (VSYNC); also elsewhere on the board
LRADC: C37.1, J12.1, R22.1; also elsewhere on the board
unnamed: C30.2, R13.2
unnamed: C33.1, C34.1, J8.4 (TCT), J8.5 (RCT), L1.1, R18.2, R19.2, R20.2, R21.2
unnamed: C35.1, J11.4 (VDD), R32.2, R33.2, R34.2, R35.1, R36.1, R37.1
unnamed: J4.R1, R9.2
unnamed: J4.R2, R8.2
unnamed: J7.1 (VBUS), JP1.2 (B)
unnamed: J7.2 (D-), R31.1
unnamed: J7.3 (D+), R30.1
unnamed: J8.9, R15.2
unnamed: J8.12, R14.2
PB2: J18.6; also elsewhere on the board
PB3: J18.5; also elsewhere on the board
PB4: J10.1; also elsewhere on the board
PB5: J10.2; also elsewhere on the board
SDC0_CLK: J11.5 (CLK); also elsewhere on the board
SDC0_CMD: J11.3 (CMD), R32.1; also elsewhere on the board
SDC0_D0: J11.7 (DAT0), R36.2; also elsewhere on the board
SDC0_D1: J11.8 (DAT1), R35.2; also elsewhere on the board
SDC0_D2: J11.1 (DAT2), R34.1; also elsewhere on the board
SDC0_D3: J11.2 (DAT3/CD), R33.1; also elsewhere on the board
SDC1_CLK: J17.1; also elsewhere on the board
SDC1_CMD: J17.2; also elsewhere on the board
SDC1_D0: J17.3; also elsewhere on the board
SDC1_D1: J17.4; also elsewhere on the board
SDC1_D2: J17.5; also elsewhere on the board
SDC1_D3: J17.6; also elsewhere on the board
SPI_CS: J9.3; also elsewhere on the board
SPI_MISO: J9.1; also elsewhere on the board
SPI_MOSI: J9.4; also elsewhere on the board
SPI_SCK: J9.2; also elsewhere on the board
UART0_RX: J2.1; also elsewhere on the board
UART0_TX: J2.2; also elsewhere on the board
UART1_RX: J3.1; also elsewhere on the board
UART1_TX: J3.2; also elsewhere on the board
UART2_RX: J5.1; also elsewhere on the board
UART2_TX: J5.2; also elsewhere on the board
USB-D+: R30.2; also elsewhere on the board
USB-D-: R31.2; also elsewhere on the board
USB-ID: J7.4 (ID); also elsewhere on the board
VLED+: LCD1.2 (LEDA); also elsewhere on the board
VLED-: LCD1.1 (LEDK); also elsewhere on the board
X24MIN: C25.1, Y1.1; also elsewhere on the board
X24MOUT: C26.1, Y1.3; also elsewhere on the board
X32KIN: C29.1, R10.1, Y2.2; also elsewhere on the board
X32KOUT: C28.1, R10.2, Y2.1; also elsewhere on the board

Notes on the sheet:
1 - GND 2 - GND 3 - RST 4 - INT 5 - SDA 6 - SCL 7 - VCC 8 - VCC
R18-R21 - вроде и без них Ethernet работает
R33-R36 скорее всего не нужны

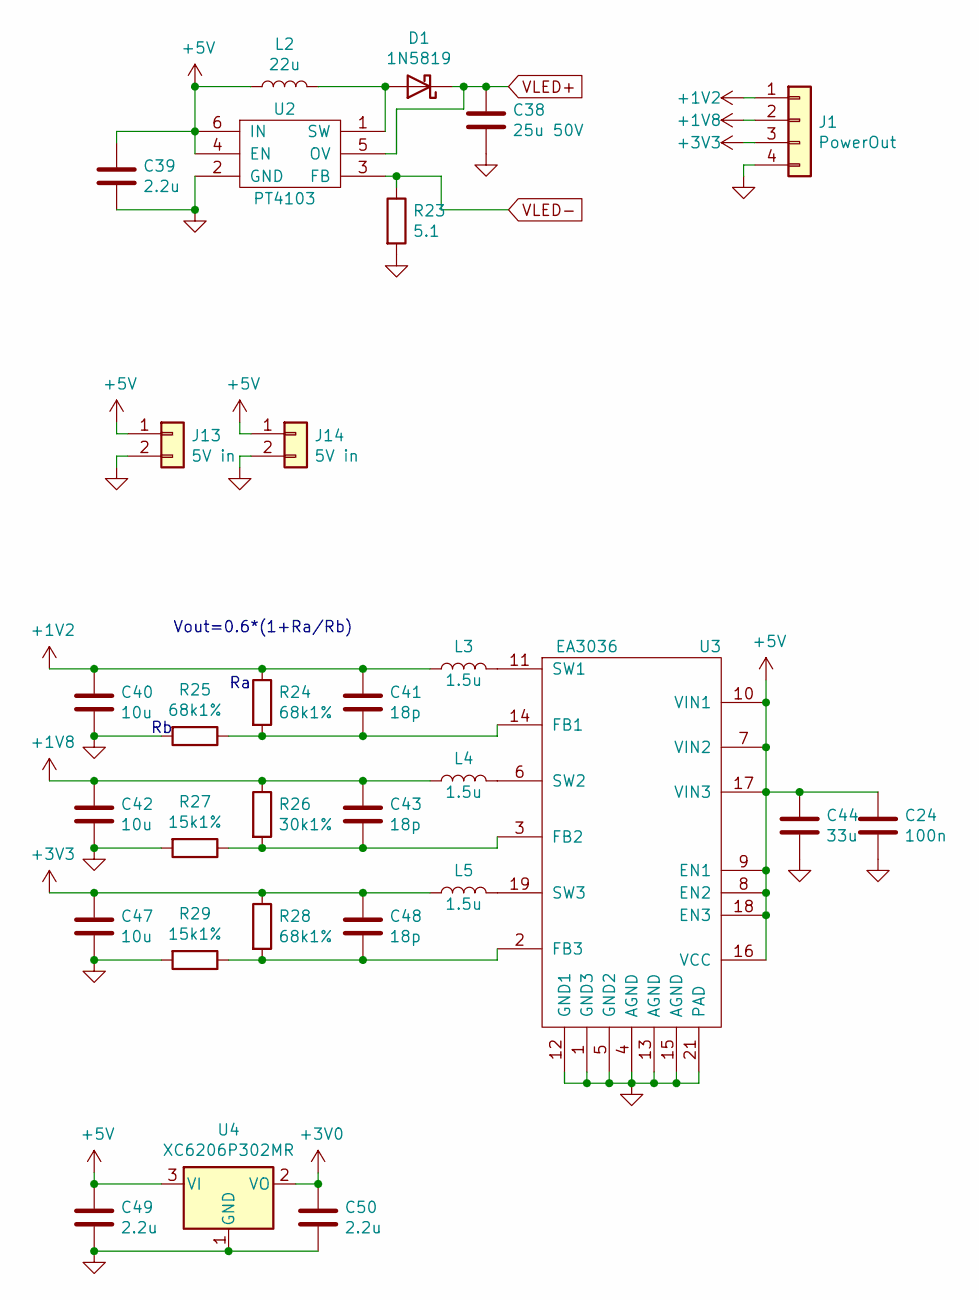
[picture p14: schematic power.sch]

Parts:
C24: 100n; C_0603_1608Metric
C38: 25u 50V; C_1206_3216Metric
C39, C49, C50: 2.2u; C_0805_2012Metric
C40, C42, C47: 10u; C_0805_2012Metric
C41, C43, C48: 18p; C_0603_1608Metric
C44: 33u; C_1206_3216Metric
D1: 1N5819; D_SOD-123
J1: PowerOut; PinSocket_1x04_P1.27mm_Vertical
J13: 5V in; PinSocket_1x02_P1.27mm_Vertical
J14: 5V in; PinSocket_1x02_P2.54mm_Vertical
L2: 22u; L_Taiyo-Yuden_NR-60xx
L3, L4, L5: 1.5u; L_TDK_SLF6045
R23: 5.1; R_0603_1608Metric
R24, R25, R28: 68k1%; R_0603_1608Metric
R26: 30k1%; R_0603_1608Metric
R27, R29: 15k1%; R_0603_1608Metric
U2: PT4103; SOT-23-6
U3: EA3036; QFN-20-1EP_3x3mm_P0.4mm_EP1.65x1.65mm_ThermalVias
U4: XC6206P302MR; SOT-23

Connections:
+1V2: C40.1, C41.1, J1.1, L3.1, R24.1; also elsewhere on the board
+1V8: C42.1, C43.1, J1.2, L4.1, R26.1; also elsewhere on the board
+3V0: C50.1, U4.2 (VO); also elsewhere on the board
+3V3: C47.1, C48.1, J1.3, L5.1, R28.1; also elsewhere on the board
+5V: C24.1, C39.1, C44.1, C49.1, J13.1, J14.1, L2.1, U2.4 (EN), U2.6 (IN), U3.7 (VIN2), U3.8 (EN2), U3.9 (EN1), U3.10 (VIN1), U3.16 (VCC), U3.17 (VIN3), U3.18 (EN3), U4.3 (VI); also elsewhere on the board
GND: C24.2, C38.2, C39.2, C40.2, C42.2, C44.2, C47.2, C49.2, C50.2, J1.4, J13.2, J14.2, R23.2, R25.2, R27.2, R29.2, U2.2 (GND), U3.1 (GND3), U3.4 (AGND), U3.5 (GND2), U3.12 (GND1), U3.13 (AGND), U3.15 (AGND), U3.21 (PAD), U4.1 (GND); also elsewhere on the board
unnamed: C41.2, R24.2, R25.1, U3.14 (FB1)
unnamed: C43.2, R26.2, R27.1, U3.3 (FB2)
unnamed: C48.2, R28.2, R29.1, U3.2 (FB3)
unnamed: D1.2 (A), L2.2, U2.1 (SW)
unnamed: L3.2, U3.11 (SW1)
unnamed: L4.2, U3.6 (SW2)
unnamed: L5.2, U3.19 (SW3)
VLED+: C38.1, D1.1 (K), U2.5 (OV); also elsewhere on the board
VLED-: R23.1, U2.3 (FB); also elsewhere on the board

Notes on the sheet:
Vout=0.6*(1+Ra/Rb)

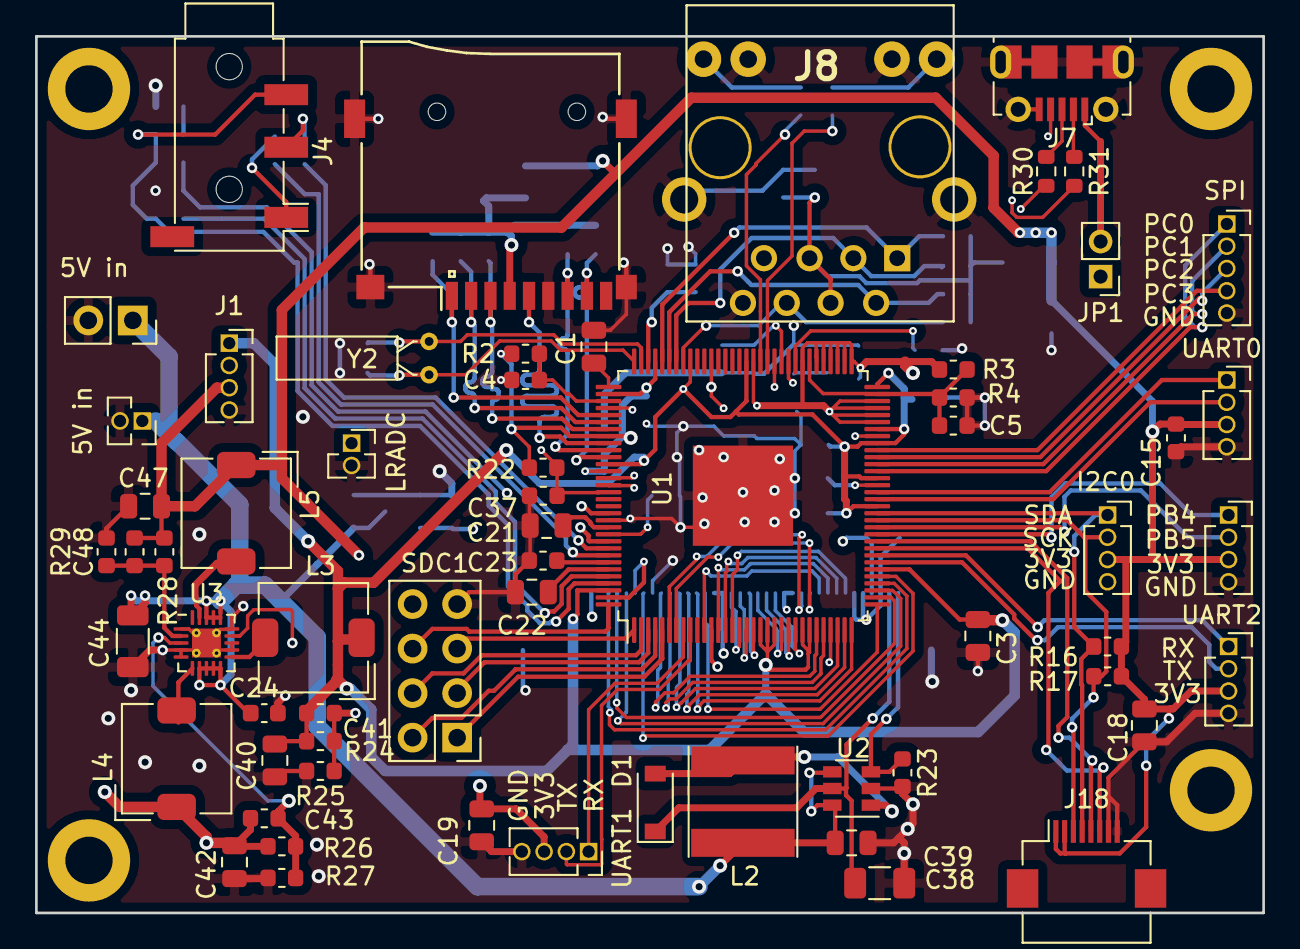
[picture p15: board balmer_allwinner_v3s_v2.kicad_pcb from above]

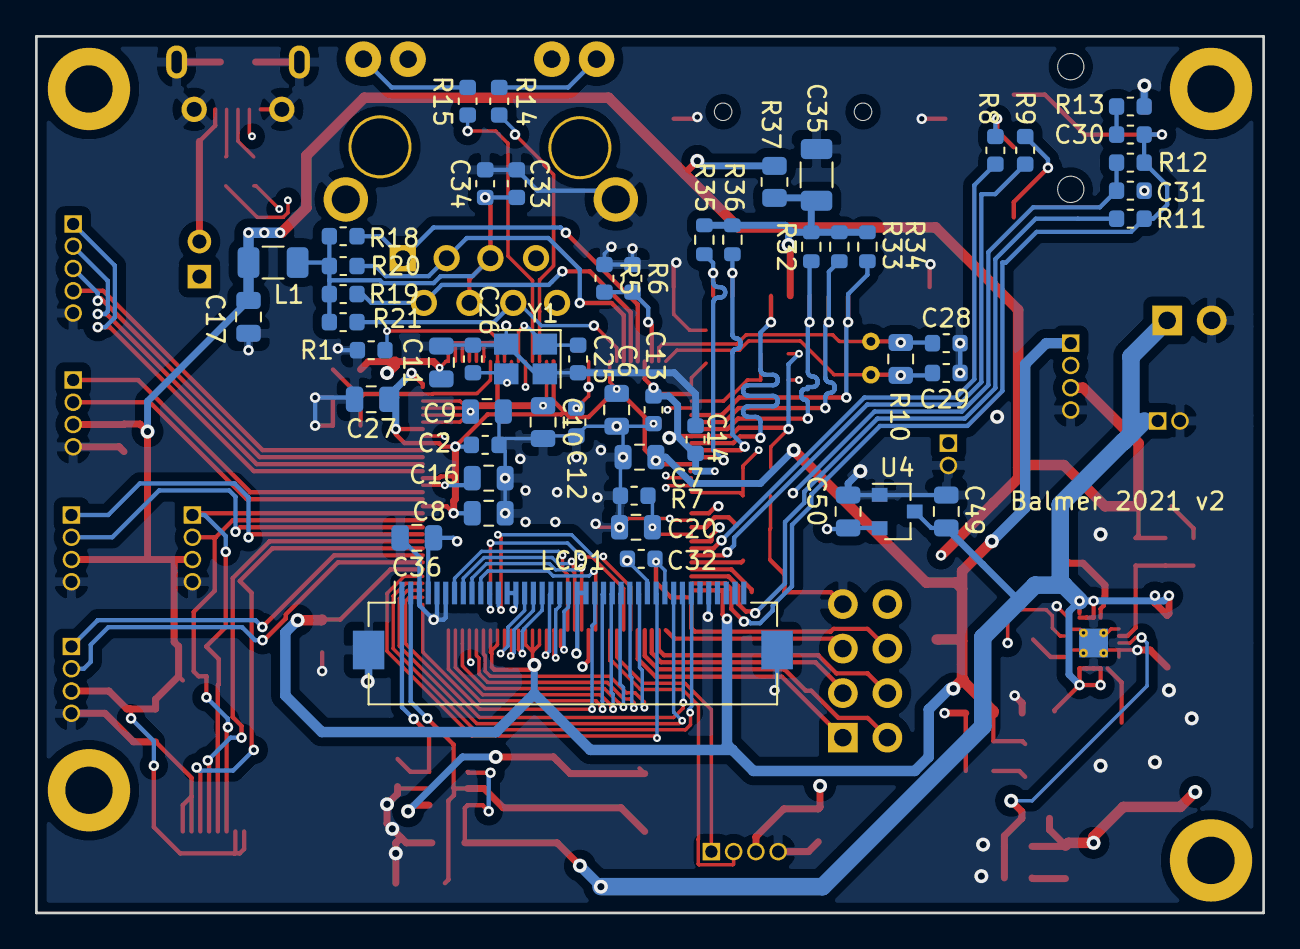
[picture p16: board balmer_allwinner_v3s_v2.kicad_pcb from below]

Board: 4 copper layers, 70.0 x 50.0 mm, 115 parts (53 on the bottom side), 103 nets.

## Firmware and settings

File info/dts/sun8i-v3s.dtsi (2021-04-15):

/*
 * Copyright (C) 2016 Icenowy Zheng <icenowy@aosc.xyz>
 *
 * This file is dual-licensed: you can use it either under the terms
 * of the GPL or the X11 license, at your option. Note that this dual
 * licensing only applies to this file, and not this project as a
 * whole.
 *
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
 * Or, alternatively,
 *
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
 *     THE SOFTWARE IS PROVIDED "AS IS", WITHOUT WARRANTY OF ANY KIND,
 *     EXPRESS OR IMPLIED, INCLUDING BUT NOT LIMITED TO THE WARRANTIES
 *     OF MERCHANTABILITY, FITNESS FOR A PARTICULAR PURPOSE AND
 *     NONINFRINGEMENT. IN NO EVENT SHALL THE AUTHORS OR COPYRIGHT
 *     HOLDERS BE LIABLE FOR ANY CLAIM, DAMAGES OR OTHER LIABILITY,
 *     WHETHER IN AN ACTION OF CONTRACT, TORT OR OTHERWISE, ARISING
 *     FROM, OUT OF OR IN CONNECTION WITH THE SOFTWARE OR THE USE OR
 *     OTHER DEALINGS IN THE SOFTWARE.
 */

#include <dt-bindings/interrupt-controller/arm-gic.h>
#include <dt-bindings/clock/sun8i-v3s-ccu.h>
#include <dt-bindings/reset/sun8i-v3s-ccu.h>

/ {
	#address-cells = <1>;
	#size-cells = <1>;
	interrupt-parent = <&gic>;

	chosen {
		#address-cells = <1>;
		#size-cells = <1>;
		ranges;

		simplefb_lcd: framebuffer@0 {
			compatible = "allwinner,simple-framebuffer",
				     "simple-framebuffer";
			allwinner,pipeline = "de0-lcd0";
			clocks = <&ccu CLK_BUS_TCON0>, <&display_clocks 0>,
				 <&display_clocks 6>, <&ccu CLK_TCON0>;
			status = "disabled";
		};
	};

	cpus {
		#address-cells = <1>;
		#size-cells = <0>;

		cpu@0 {
			compatible = "arm,cortex-a7";
			device_type = "cpu";
			reg = <0>;
			clocks = <&ccu CLK_CPU>;
		};
	};

	de: display-engine {
		compatible = "allwinner,sun8i-v3s-display-engine";
		allwinner,pipelines = <&mixer0>;
		status = "disabled";
	};

	timer {
		compatible = "arm,armv7-timer";
		interrupts = <GIC_PPI 13 (GIC_CPU_MASK_SIMPLE(4) | IRQ_TYPE_LEVEL_LOW)>,
			     <GIC_PPI 14 (GIC_CPU_MASK_SIMPLE(4) | IRQ_TYPE_LEVEL_LOW)>,
			     <GIC_PPI 11 (GIC_CPU_MASK_SIMPLE(4) | IRQ_TYPE_LEVEL_LOW)>,
			     <GIC_PPI 10 (GIC_CPU_MASK_SIMPLE(4) | IRQ_TYPE_LEVEL_LOW)>;
	};

	clocks {
		#address-cells = <1>;
		#size-cells = <1>;
		ranges;

		osc24M: osc24M_clk {
			#clock-cells = <0>;
			compatible = "fixed-clock";
			clock-frequency = <24000000>;
			clock-output-names = "osc24M";
		};

		osc32k: osc32k_clk {
			#clock-cells = <0>;
			compatible = "fixed-clock";
			clock-frequency = <32768>;
			clock-output-names = "osc32k";
		};
	};

	soc {
		compatible = "simple-bus";
		#address-cells = <1>;
		#size-cells = <1>;
		ranges;

		display_clocks: clock@1000000 {
			compatible = "allwinner,sun8i-v3s-de2-clk";
			reg = <0x01000000 0x100000>;
			clocks = <&ccu CLK_DE>,
				 <&ccu CLK_BUS_DE>;
			clock-names = "mod",
				      "bus";
			resets = <&ccu RST_BUS_DE>;
			#clock-cells = <1>;
			#reset-cells = <1>;
		};

		mixer0: mixer@1100000 {
			compatible = "allwinner,sun8i-v3s-de2-mixer";
			reg = <0x01100000 0x100000>;
			clocks = <&display_clocks 0>,
				 <&display_clocks 6>;
			clock-names = "bus",
				      "mod";
			resets = <&display_clocks 0>;
			assigned-clocks = <&display_clocks 6>;
			assigned-clock-rates = <150000000>;

			ports {
				#address-cells = <1>;
				#size-cells = <0>;

				mixer0_out: port@1 {
					#address-cells = <1>;
					#size-cells = <0>;
					reg = <1>;

					mixer0_out_tcon0: endpoint@0 {
						reg = <0>;
						remote-endpoint = <&tcon0_in_mixer0>;
					};
				};
			};
		};

		syscon: syscon@1c00000 {
			compatible = "allwinner,sun8i-v3s-system-controller",
				"syscon";
			reg = <0x01c00000 0x1000>;
		};

		tcon0: lcd-controller@1c0c000 {
			compatible = "allwinner,sun8i-v3s-tcon";
			reg = <0x01c0c000 0x1000>;
			interrupts = <GIC_SPI 86 IRQ_TYPE_LEVEL_HIGH>;
			clocks = <&ccu CLK_BUS_TCON0>,
				 <&ccu CLK_TCON0>;
			clock-names = "ahb",
				      "tcon-ch0";
			clock-output-names = "tcon-pixel-clock";
			resets = <&ccu RST_BUS_TCON0>;
			reset-names = "lcd";
			status = "disabled";

			ports {
				#address-cells = <1>;
				#size-cells = <0>;

				tcon0_in: port@0 {
					#address-cells = <1>;
					#size-cells = <0>;
					reg = <0>;

					tcon0_in_mixer0: endpoint@0 {
						reg = <0>;
						remote-endpoint = <&mixer0_out_tcon0>;
					};
				};

				tcon0_out: port@1 {
					#address-cells = <1>;
					#size-cells = <0>;
					reg = <1>;
				};
			};
		};


		dma: dma-controller@01c02000 {
			compatible = "allwinner,sun8i-v3s-dma";
			reg = <0x01c02000 0x1000>;
			interrupts = <GIC_SPI 50 IRQ_TYPE_LEVEL_HIGH>;
			clocks = <&ccu CLK_BUS_DMA>;
			resets = <&ccu RST_BUS_DMA>;
			#dma-cells = <1>;
		};

		mmc0: mmc@01c0f000 {
			compatible = "allwinner,sun7i-a20-mmc";
			reg = <0x01c0f000 0x1000>;
			clocks = <&ccu CLK_BUS_MMC0>,
				 <&ccu CLK_MMC0>,
				 <&ccu CLK_MMC0_OUTPUT>,
				 <&ccu CLK_MMC0_SAMPLE>;
			clock-names = "ahb",
				      "mmc",
				      "output",
				      "sample";
			resets = <&ccu RST_BUS_MMC0>;
			reset-names = "ahb";
			interrupts = <GIC_SPI 60 IRQ_TYPE_LEVEL_HIGH>;
			status = "disabled";
			#address-cells = <1>;
			#size-cells = <0>;
		};

		mmc1: mmc@01c10000 {
			compatible = "allwinner,sun7i-a20-mmc";
			reg = <0x01c10000 0x1000>;
			clocks = <&ccu CLK_BUS_MMC1>,
				 <&ccu CLK_MMC1>,
				 <&ccu CLK_MMC1_OUTPUT>,
				 <&ccu CLK_MMC1_SAMPLE>;
			clock-names = "ahb",
				      "mmc",
				      "output",
				      "sample";
			resets = <&ccu RST_BUS_MMC1>;
			reset-names = "ahb";
			interrupts = <GIC_SPI 61 IRQ_TYPE_LEVEL_HIGH>;
			pinctrl-names = "default";
			pinctrl-0 = <&mmc1_pins>;
			status = "disabled";
			#address-cells = <1>;
			#size-cells = <0>;
		};

		mmc2: mmc@01c11000 {
			compatible = "allwinner,sun7i-a20-mmc";
			reg = <0x01c11000 0x1000>;
			clocks = <&ccu CLK_BUS_MMC2>,
				 <&ccu CLK_MMC2>,
				 <&ccu CLK_MMC2_OUTPUT>,
				 <&ccu CLK_MMC2_SAMPLE>;
			clock-names = "ahb",
				      "mmc",
				      "output",
				      "sample";
			resets = <&ccu RST_BUS_MMC2>;
			reset-names = "ahb";
			interrupts = <GIC_SPI 62 IRQ_TYPE_LEVEL_HIGH>;
			status = "disabled";
			#address-cells = <1>;
			#size-cells = <0>;
		};

		usb_otg: usb@01c19000 {
			compatible = "allwinner,sun8i-h3-musb";
			reg = <0x01c19000 0x0400>;
			clocks = <&ccu CLK_BUS_OTG>;
			resets = <&ccu RST_BUS_OTG>;
			interrupts = <GIC_SPI 71 IRQ_TYPE_LEVEL_HIGH>;
			interrupt-names = "mc";
			phys = <&usbphy 0>;
			phy-names = "usb";
			extcon = <&usbphy 0>;
			status = "disabled";
		};

		usbphy: phy@01c19400 {
			compatible = "allwinner,sun8i-v3s-usb-phy";
			reg = <0x01c19400 0x2c>,
			      <0x01c1a800 0x4>;
			reg-names = "phy_ctrl",
				    "pmu0";
			clocks = <&ccu CLK_USB_PHY0>;
			clock-names = "usb0_phy";
			resets = <&ccu RST_USB_PHY0>;
			reset-names = "usb0_reset";
			status = "disabled";
			#phy-cells = <1>;
		};
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

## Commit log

2021-04-15 - schematic & initial docs
    [balmer_allwinner_v3s_v2.kicad_pcb, balmer_allwinner_v3s_v2.sch, periphery.sch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]
2021-05-08 - кусочек коробочки

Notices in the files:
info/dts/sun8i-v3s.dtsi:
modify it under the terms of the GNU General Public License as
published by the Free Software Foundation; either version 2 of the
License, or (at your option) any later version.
